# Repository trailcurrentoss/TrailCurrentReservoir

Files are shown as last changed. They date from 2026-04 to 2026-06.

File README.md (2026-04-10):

# TrailCurrent Reservoir

Water tank level monitoring module that reads contactless level sensors on up to three tanks (fresh, grey, black water) and transmits fill percentages over a CAN bus interface. Part of the [TrailCurrent](https://trailcurrent.com) open-source vehicle platform.

## Hardware Overview

- **Board:** Waveshare ESP32-S3-RS485-CAN
- **Microcontroller:** ESP32-S3
- **Framework:** ESP-IDF with FreeRTOS
- **Function:** Contactless water level sensors to CAN bus bridge
- **Key Features:**
  - Monitors up to 3 water tanks (fresh, grey, black)
  - 4 contactless level sensors per tank (25%, 50%, 75%, 100%)
  - Reports tank levels as 0-100% over CAN bus
  - Percentage-based protocol supports future migration to analog sensors
  - CAN bus output at 500 kbps (TWAI normal mode)
  - Automatic CAN bus recovery from bus-off errors
  - Nodes can enter and leave the network without disrupting the bus
  - Dedicated FreeRTOS tasks for CAN and sensor polling
  - CAN-triggered OTA firmware updates over WiFi (HTTP upload)
  - WiFi credential provisioning via CAN bus
  - Dual OTA partition table for safe updates with rollback
  - 80 MHz CPU clock for reduced power consumption

## Hardware Requirements

### Components

- **Board:** [Waveshare ESP32-S3-RS485-CAN](https://www.waveshare.com/wiki/ESP32-S3-RS485-CAN#Schematic)
- **CAN Bus:** Built-in transceiver (TX: GPIO 15, RX: GPIO 16, 500 kbps)
- **Sensors:** 12x contactless water level sensors (active HIGH output when water detected)
- **Debug Console:** USB CDC (115200 baud)

### Pin Assignments

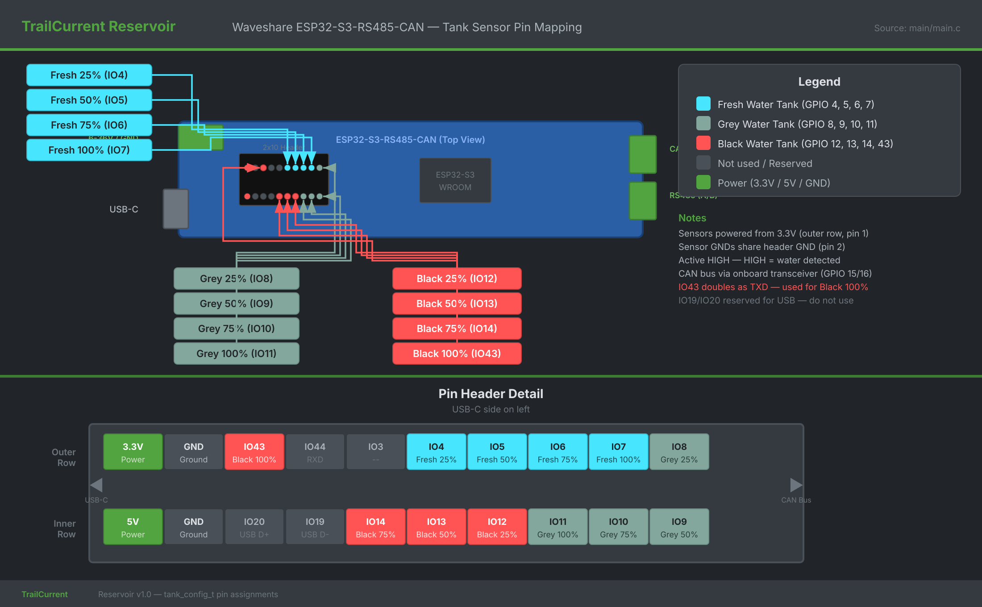
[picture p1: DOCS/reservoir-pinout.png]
Board Pin Mapping


| Function | GPIO | Description |
|---|---|---|
| CAN TX | 15 | CAN bus transmit (onboard transceiver) |
| CAN RX | 16 | CAN bus receive (onboard transceiver) |
| Fresh 25% | 4 | Fresh water tank, 25% level sensor |
| Fresh 50% | 5 | Fresh water tank, 50% level sensor |
| Fresh 75% | 6 | Fresh water tank, 75% level sensor |
| Fresh 100% | 7 | Fresh water tank, 100% level sensor |
| Grey 25% | 8 | Grey water tank, 25% level sensor |
| Grey 50% | 9 | Grey water tank, 50% level sensor |
| Grey 75% | 10 | Grey water tank, 75% level sensor |
| Grey 100% | 11 | Grey water tank, 100% level sensor |
| Black 25% | 12 | Black water tank, 25% level sensor |
| Black 50% | 13 | Black water tank, 50% level sensor |
| Black 75% | 14 | Black water tank, 75% level sensor |
| Black 100% | 43 | Black water tank, 100% level sensor |

All sensor GPIOs are configured as inputs with internal pull-down resistors.

### Ribbon Cable Pinout

When connecting via a 20-pin IDC ribbon cable, the red stripe aligns with pin 1 (3.3V/5V end). The sensor wires are interleaved due to standard odd/even row numbering.

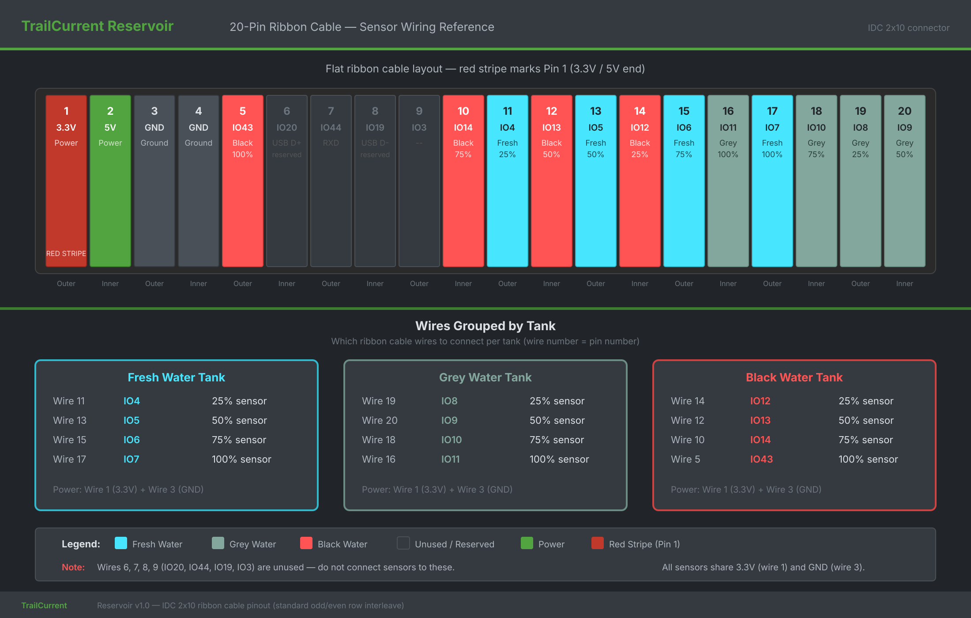
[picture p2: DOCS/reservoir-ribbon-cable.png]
Ribbon Cable Pinout


## Firmware

The firmware uses ESP-IDF with FreeRTOS. Source is in the `main/` directory.

### Prerequisites

- [ESP-IDF v5.5+](https://docs.espressif.com/projects/esp-idf/en/stable/esp32s3/get-started/)

### Build and Flash

```bash
# Set ESP-IDF environment
. $HOME/esp/esp-idf/export.sh

# Build
idf.py build

# Flash via USB (development)
idf.py -p /dev/ttyACM0 flash

# Monitor serial output
idf.py -p /dev/ttyACM0 monitor
```

### Creating Release Binaries

The standard `idf.py build` produces `build/reservoir.bin` — the application image only. This is the correct binary for OTA updates, where Headwaters writes it directly to an app partition via the device's `/ota` HTTP endpoint.

The TrailCurrent web flasher needs a different binary: a merged image containing the bootloader, partition table, OTA data, and application combined into a single file that gets flashed at offset 0x0. Without this, the web flasher would write the application binary to the wrong flash offset, resulting in a non-booting device.

After building, run the merge script to create the merged binary:

```bash
idf.py build
./merge.sh
```

This produces two files in `build/`:

| File | Contents | Used By |
|---|---|---|
| `reservoir.bin` | Application image only | Headwaters OTA (`deploy.sh`, `ota.js`), direct `curl` uploads |
| `reservoir_merged.bin` | Bootloader + partition table + OTA data + application | Web flasher (full flash at 0x0) |

**Both files must be attached to each GitHub release:**

```bash
git tag -a v1.0.0 -m "Firmware release v1.0.0"
git push origin v1.0.0

gh release create v1.0.0 \
  build/reservoir.bin \
  build/reservoir_merged.bin \
  --repo trailcurrentoss/TrailCurrentReservoir \
  --title "v1.0.0" \
  --notes "Firmware release v1.0.0"
```

The web flasher matches `reservoir_merged.bin` by the "merged" keyword in the filename. The Headwaters deployment system (`fetch-firmware.sh`) downloads the app-only `reservoir.bin` for OTA delivery.

### Architecture

The firmware runs two FreeRTOS tasks:

- **Main task** - Polls all 12 water level sensor GPIOs every 500ms and converts binary sensor states to tank fill percentages.
- **TWAI task** - Manages the CAN bus independently on core 1. Handles bus-off detection, automatic recovery, and periodic non-blocking transmission of tank levels. Bus errors never stall sensor polling.

See [DOCS/firmware-architecture.md](DOCS/firmware-architecture.md) for detailed architecture documentation.

### CAN Bus Recovery

The TWAI driver runs in **normal mode** with full alert handling:

1. **Bus-off detected** - Transmissions stop, `twai_initiate_recovery()` is called
2. **Bus recovered** - Driver restarts via `twai_start()`, transmissions resume
3. **Error passive** - Logged as a warning (typically means no peers are ACKing)

This allows nodes to be connected and disconnected from the bus at any time without crashing the firmware or requiring a reboot.

### Sensor Reading Logic

Water rises from bottom to top, triggering sensors sequentially. The reported level equals the highest sensor reading HIGH:

| Sensors Triggered | Reported Level |
|---|---|
| None | 0% |
| 25% only | 25% |
| 25% + 50% | 50% |
| 25% + 50% + 75% | 75% |
| All four | 100% |

If a tank is not physically connected, all its sensors remain LOW and the level reports 0%.

### CAN Bus Protocol

The device communicates at 500 kbps using standard 11-bit CAN IDs.

**Received Messages:**

| CAN ID | Name | Description |
|---|---|---|
| 0x00 | OTA Trigger | 3 bytes: target device MAC (last 3 bytes). Enters OTA mode if matched. |
| 0x01 | WiFi Config | Chunked credential provisioning (start/SSID chunks/password chunks/end). |
| 0x02 | Discovery | Broadcast trigger for mDNS self-discovery. |

**Transmitted Messages:**

| CAN ID | Name | Cycle | Description |
|---|---|---|---|
| 0x04 | Version Report | Once at boot | `[mac3, mac4, mac5, major, minor, patch]` |
| 0x3E | WaterTankLevels | 1000ms | 3 bytes: fresh %, grey %, black % |

**Message 0x3E - WaterTankLevels** (3 bytes):

| Byte | Signal | Range | Unit | Description |
|---|---|---|---|---|
| 0 | FreshWaterLevel | 0-100 | % | Fresh water tank fill level |
| 1 | GreyWaterLevel | 0-100 | % | Grey water tank fill level |
| 2 | BlackWaterLevel | 0-100 | % | Black water tank fill level |

See [DOCS/can-protocol.md](DOCS/can-protocol.md) for full protocol details including encoding examples and future analog sensor considerations.

### OTA Firmware Updates

The device supports over-the-air firmware updates triggered via CAN bus, matching the TrailCurrent OTA protocol used across all nodes.

**How it works:**

1. Headwaters (Raspberry Pi) sends CAN ID `0x00` with the target device's last 3 MAC bytes
2. If the MAC matches, the device connects to WiFi and starts an HTTP server
3. Firmware is uploaded via HTTP POST to the device
4. After upload, the device reboots into the new firmware
5. If no upload arrives within 3 minutes, WiFi disconnects and normal operation resumes

**Uploading firmware:**

OTA writes only to the app partition, so always use `reservoir.bin` (the app-only binary), never `reservoir_merged.bin`. The merged binary contains the bootloader and partition table, which would fail the app image validation in `esp_ota_end`.

```bash
# Find device hostname from serial output (e.g., esp32-8A3B4C)
# After OTA mode is triggered:
curl -X POST http://esp32-XXYYZZ.local/ota --data-binary @build/reservoir.bin
```

**WiFi credential provisioning:**

WiFi credentials are stored in NVS and provisioned via CAN ID `0x01` using a chunked message protocol. See the TrailCurrent CAN Bus Reference for the full specification.

**Partition layout:**

The device uses a dual OTA partition scheme for safe updates with automatic rollback:

| Partition | Type | Size |
|---|---|---|
| nvs | data (nvs) | 20 KB |
| otadata | data (ota) | 8 KB |
| app0 | app (ota_0) | 1792 KB |
| app1 | app (ota_1) | 1792 KB |
| spiffs | data (spiffs) | 448 KB |

## Documentation

Detailed documentation is available in the [DOCS/](DOCS/) directory:

- [High-Level Requirements](DOCS/Requirements/high-level-requirements.md) - System requirements and design rationale
- [Firmware Architecture](DOCS/firmware-architecture.md) - Task structure, data flow, and timing
- [CAN Protocol](DOCS/can-protocol.md) - Complete CAN message specification
- [Sensor Wiring Guide](DOCS/sensor-wiring.md) - Installation, wiring, and troubleshooting
- [Board Pin Mapping](DOCS/reservoir-pinout.svg) - GPIO-to-sensor visual pin diagram
- [Ribbon Cable Pinout](DOCS/reservoir-ribbon-cable.svg) - 20-pin IDC ribbon cable wiring reference

## Project Structure

```
├── DOCS/                             # Detailed documentation
│   ├── Requirements/
│   │   └── high-level-requirements.md
│   ├── firmware-architecture.md
│   ├── can-protocol.md
│   ├── sensor-wiring.md
│   ├── reservoir-pinout.svg          # Board pin mapping diagram
│   ├── reservoir-pinout.png
│   ├── reservoir-ribbon-cable.svg    # Ribbon cable wiring diagram
│   └── reservoir-ribbon-cable.png
├── main/                             # ESP-IDF firmware source
│   ├── main.c                        # Sensor polling and CAN transmitter
│   ├── wifi_config.c                 # WiFi credential management via CAN
│   ├── wifi_config.h
│   ├── ota.c                         # OTA update, WiFi, mDNS
│   ├── ota.h
│   ├── discovery.c                   # mDNS self-discovery
│   ├── discovery.h
│   ├── idf_component.yml             # Component dependencies
│   └── CMakeLists.txt                # Component registration
├── partitions.csv                    # Dual OTA partition table
├── CMakeLists.txt                    # ESP-IDF root build file
├── merge.sh                          # Creates merged binary for web flasher / releases
└── sdkconfig.defaults                # ESP-IDF default configuration
```

## License

MIT License - See LICENSE file for details.

This is open source hardware. You are free to use, modify, and distribute these designs under the terms of the MIT license.

## Contributing

Improvements and contributions are welcome! Please submit issues or pull requests.

## Support

For questions about:
- **KiCAD setup:** See [KICAD_ENVIRONMENT_SETUP.md](https://github.com/trailcurrentoss/TrailCurrentKiCADLibraries/blob/main/KICAD_ENVIRONMENT_SETUP.md)
- **Assembly workflow:** See [BOM_ASSEMBLY_WORKFLOW.md](https://github.com/trailcurrentoss/TrailCurrentKiCADLibraries/blob/main/BOM_ASSEMBLY_WORKFLOW.md)

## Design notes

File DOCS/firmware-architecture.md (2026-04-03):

# Firmware Architecture

## Overview

The Reservoir firmware is an ESP-IDF application that polls contactless water level sensors and broadcasts tank fill percentages over a CAN bus. It follows the same architectural patterns as other TrailCurrent modules (Ampline, Solstice, Picket) with dedicated FreeRTOS tasks for CAN and application logic.

## Task Structure

| Task | Core | Priority | Stack | Function |
|---|---|---|---|---|
| Main (app_main) | 0 | 1 (default) | default | Sensor polling loop |
| TWAI | 1 | 5 | 4096 B | CAN bus TX/RX and error handling |
| OTA | any | 3 | 8192 B | On-demand: WiFi + HTTP OTA server |
| Discovery | any | 3 | 8192 B | On-demand: mDNS registration |

The OTA and Discovery tasks are mutually exclusive and only run when triggered by a CAN message. They are created dynamically and delete themselves on completion.

## Data Flow

```
Sensors (GPIO)          Shared Memory           CAN Bus
 ┌──────────┐          ┌──────────────┐        ┌──────────┐
 │ 12 GPIOs │──poll──> │ tank_levels  │──read─>│ TWAI TX  │──> CAN ID 0x3E
 │ (500ms)  │          │ [3 x uint8]  │        │ (1000ms) │
 └──────────┘          └──────────────┘        └──────────┘
   Main Task            volatile array          TWAI Task
```

1. **Main task** reads all 12 GPIO pins every 500ms
2. For each tank, it determines the highest triggered sensor and writes the percentage to `tank_levels[]`
3. **TWAI task** reads `tank_levels[]` every 1000ms and packs it into a 3-byte CAN message
4. Single-writer (main task) / single-reader (TWAI task) pattern with `volatile` — no mutex needed

## Sensor-to-Percentage Conversion

Each tank has 4 sensors mounted at physical water levels corresponding to 25%, 50%, 75%, and 100%. The sensors are indexed from lowest (index 0 = 25%) to highest (index 3 = 100%).

```c
static uint8_t read_tank_level(const tank_config_t *tank)
{
    uint8_t level = 0;
    for (int s = 0; s < NUM_SENSORS; s++) {
        if (gpio_get_level(tank->pins[s])) {
            level = (s + 1) * 25;
        }
    }
    return level;
}
```

The loop iterates from the lowest sensor upward. Each HIGH sensor overwrites the level, so the final value is the highest triggered sensor. This handles the normal case where water triggers all sensors below the surface.

**Edge cases:**

| Scenario | Sensor States (25/50/75/100) | Result |
|---|---|---|
| Empty tank | LOW/LOW/LOW/LOW | 0% |
| Quarter full | HIGH/LOW/LOW/LOW | 25% |
| Half full | HIGH/HIGH/LOW/LOW | 50% |
| Three-quarter full | HIGH/HIGH/HIGH/LOW | 75% |
| Full | HIGH/HIGH/HIGH/HIGH | 100% |
| No tank connected | LOW/LOW/LOW/LOW | 0% |
| Sensor skip (50% stuck LOW) | HIGH/LOW/HIGH/LOW | 75% |

The last case (sensor skip) reports the highest triggered sensor regardless of gaps. This is intentional — a stuck-low sensor should not suppress the reading from higher sensors.

## GPIO Configuration

All 12 sensor GPIOs are configured in a single `gpio_config()` call at startup:

- **Mode:** Input
- **Pull-up:** Disabled
- **Pull-down:** Enabled (internal)
- **Interrupt:** Disabled (polling-based)

The internal pull-down ensures a clean LOW reading when no sensor is connected or when the sensor is not triggered. The contactless sensors drive the GPIO HIGH when water is detected.

## CAN Bus State Machine

The TWAI task implements the same bus state machine used across all TrailCurrent modules:

```
                 ┌─────────────┐
     boot ──────>│  TX_ACTIVE  │<──── TX_SUCCESS or RX_DATA
                 │  (1000ms)   │
                 └──────┬──────┘
                        │ 3x TX_FAILED
                        v
                 ┌─────────────┐
                 │ TX_PROBING  │───── TX_SUCCESS ────> TX_ACTIVE
                 │  (2000ms)   │
                 └──────┬──────┘
                        │ BUS_OFF
                        v
                 ┌─────────────┐
                 │  RECOVERY   │───── BUS_RECOVERED ──> TX_PROBING
                 │  (waiting)  │
                 └─────────────┘
```

- **TX_ACTIVE:** Normal operation, transmits every 1000ms
- **TX_PROBING:** No peers on bus, slows to 2000ms to reduce error load
- **RECOVERY:** Bus-off detected, driver recovery in progress, no transmissions

## Startup Sequence

1. Initialize NVS and load WiFi credentials (if previously provisioned)
2. Initialize Discovery and OTA subsystems
3. Configure all 12 sensor GPIOs with pull-downs
4. Log hostname and pin assignments
5. Start TWAI task on core 1
6. Broadcast firmware version on CAN ID 0x04
7. Enter main loop: poll sensors every 500ms

## Source Files

| File | Lines | Purpose |
|---|---|---|
| `main.c` | ~250 | Sensor GPIO config, polling, TWAI task, CAN message packing |
| `wifi_config.c` | ~280 | NVS credential storage, CAN-based WiFi provisioning state machine |
| `wifi_config.h` | ~15 | WiFi config public API |
| `ota.c` | ~220 | HTTP OTA server, firmware write, CAN trigger handling |
| `ota.h` | ~28 | OTA public API |
| `discovery.c` | ~175 | mDNS advertisement, Headwaters confirmation endpoint |
| `discovery.h` | ~28 | Discovery public API |

## Timing Summary

| Event | Interval | Notes |
|---|---|---|
| Sensor poll | 500ms | Main task loop delay |
| CAN TX (active) | 1000ms | Normal operation with peers |
| CAN TX (probing) | 2000ms | No peers detected |
| WiFi config timeout | 5s | Resets chunked credential state machine |
| OTA timeout | 3 min | Disconnects WiFi if no upload received |
| Discovery timeout | 3 min | Disconnects WiFi if no confirmation |

## Memory Usage

The firmware has minimal RAM requirements:

- **Shared state:** 3 bytes (`tank_levels[3]`, volatile uint8)
- **No heap allocations** in the sensor polling or CAN transmission paths
- **Stack sizes:** Main task uses default (~3.5 KB), TWAI task uses 4 KB
- **OTA/Discovery:** 8 KB stack each, only allocated when triggered

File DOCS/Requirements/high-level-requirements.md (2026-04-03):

# High-Level Design (HLD) Document

## 1. Project Overview

**Project Title:** Reservoir Module

**Description:** A microcontroller-based system that monitors the fill level of up to three water tanks (fresh, grey, black) using contactless level sensors and reports the data over CAN bus. It enables the TrailCurrent platform to display real-time water levels and trigger alerts when tanks are full or empty.

**Objective:**
To design and implement a reliable, low-power, and cost-effective water tank monitoring system that reports fill levels as percentages over CAN bus, with a protocol that supports future migration from binary contactless sensors to analog level sensors without any CAN message format changes.

---

## 2. Microcontroller Selection

**Selected Microcontroller:**
**ESP32-S3** (Waveshare ESP32-S3-RS485-CAN)
[Datasheet](https://www.espressif.com/sites/default/files/documentation/esp32-s3_datasheet_en.pdf)

**Rationale for Selection:**
- Off-the-shelf board with onboard CAN transceiver (TJA1051), buck converter (7-36V), and 20-pin header for sensor connections.
- 12 GPIOs available on pin header with internal pull-downs for sensor inputs.
- Strong ecosystem and ESP-IDF development support.
- Shared board with Solstice and Picket modules, reducing BOM complexity.
- No external pull-down resistors needed (internal pull-downs are sufficient for active-high sensor outputs).

---

## 3. System Requirements

### 3.1 Functional Requirements

| Requirement | Description |
|---|---|
| Tank Level Sensing | Read contactless water level sensors and determine fill level for each of 3 tanks |
| Percentage Reporting | Report each tank level as a 0-100% value, not as individual sensor states |
| CAN Transmission | Broadcast all 3 tank levels in a single CAN message at 1-second intervals |
| Multi-Tank Support | Support fresh water, grey water, and black water tanks independently |
| Graceful Degradation | Report 0% for any tank that has no sensors connected |
| OTA Updates | Support over-the-air firmware updates triggered via CAN bus |
| WiFi Provisioning | Accept WiFi credentials via CAN bus for OTA connectivity |
| Network Discovery | Respond to mDNS discovery broadcasts for Headwaters registration |

### 3.2 Non-Functional Requirements

| Requirement | Description |
|---|---|
| Reliability | System must operate continuously without disruption indefinitely for solar/off-grid installs |
| Protocol Agnosticism | CAN message format must not change if sensors are upgraded from binary to analog |
| Power Consumption | 80 MHz CPU clock to minimize power draw on house battery systems |
| Environmental Tolerance | Operate within -20C to +70C |
| Response Time | Sensor polling at 500ms intervals for timely level updates |
| Bus Resilience | CAN bus errors must not halt sensor polling; automatic bus recovery required |

---

## 4. System Architecture Overview

### 4.1 Hardware Components

| Component | Description |
|---|---|
| ESP32-S3 (Waveshare ESP32-S3-RS485-CAN) | Main microcontroller with onboard CAN transceiver |
| Contactless Water Level Sensors (x12) | Active-high output sensors, 4 per tank at 25/50/75/100% marks |
| CAN Bus Wiring | Standard 2-wire CAN bus (CANH, CANL) with 120-ohm termination |

### 4.2 Software Components

| Component | Description |
|---|---|
| Main Application | Sensor polling, level calculation, and shared data management |
| TWAI Task | CAN bus communication, error handling, and periodic message transmission |
| WiFi Config | NVS-backed WiFi credential storage with CAN-based provisioning |
| OTA | Over-the-air firmware update via HTTP with CAN-triggered activation |
| Discovery | mDNS-based module registration with Headwaters |

---

## 5. Communication Protocol

- **CAN Bus:** 500 kbps, standard 11-bit IDs, TWAI normal mode
- **Message ID:** 0x3E (WaterTankLevels)
- **Data Format:** 3 bytes, each a uint8 representing 0-100% fill level
- **Transmission Frequency:** 1 Hz (1000ms cycle), slows to 0.5 Hz when no CAN peers detected
- **Byte Layout:** `[fresh%, grey%, black%]`

### Protocol Design Decision: Percentages Over Sensor States

The CAN protocol transmits percentage values (0-100) rather than individual sensor booleans. This is intentional:

- **Current sensors (contactless binary):** Values are quantized to 0/25/50/75/100%
- **Future sensors (analog/continuous):** Values can be any integer 0-100%
- **CAN message format stays identical** regardless of sensor technology
- Receivers (Headwaters, mobile app, dashboards) never need to know how the percentage was derived

---

## 6. Power Management Strategy

- **Battery:** Connected to house battery of implemented vehicle
- **Power Supply Circuit:** Waveshare board includes 7-36V input with onboard buck converter and 3.3V regulator
- **CPU Clock:** 80 MHz (reduced from default 240 MHz) for lower power consumption
- **Sleep Modes:** Not used; the module must report continuously for real-time monitoring

---

## 7. Development Tools and Environment

| Tool | Description |
|---|---|
| ESP-IDF | Development framework (v5.5+) |
| VS Code | Development IDE |
| KiCAD | EDA design tool for schematic and PCB (future hardware design) |
| FreeCAD | CAD tool for enclosure design (future) |
| Version Control | Git with GitHub for repo and source control |
| Documentation Tools | Markdown |

---

## 8. Testing and Validation

| Test Type | Description |
|---|---|
| Unit Testing | Verify sensor-to-percentage conversion logic for all input combinations |
| Integration Testing | Validate CAN message transmission with Headwaters and mobile app |
| Sensor Validation | Test with sensors submerged at known water levels to confirm correct reporting |
| Bus Resilience | Disconnect and reconnect CAN bus during operation; verify automatic recovery |
| OTA Testing | Trigger OTA update via CAN; verify firmware upload and reboot cycle |
| Multi-Tank | Test with 1, 2, and 3 tanks connected to verify independent reporting |

---

## 9. Future Enhancements

- Migrate to analog level sensors for continuous 0-100% reporting (no CAN protocol changes needed)
- Add temperature compensation for sensor readings
- Add leak detection (unexpected level drop alerts)
- Add tank capacity configuration via CAN for volumetric reporting (liters/gallons)
- Hardware design (KiCAD schematic, PCB, FreeCAD enclosure) for a dedicated Reservoir board

---

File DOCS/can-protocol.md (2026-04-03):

# CAN Bus Protocol

## Bus Configuration

| Parameter | Value |
|---|---|
| Bit Rate | 500 kbps |
| ID Format | Standard (11-bit) |
| Mode | TWAI Normal |
| Filter | Accept all |

## Message Summary

### Transmitted by Reservoir

| CAN ID | Name | DLC | Cycle | Description |
|---|---|-----|---|---|
| 0x04 | FirmwareVersionReport | 6 | Once at boot | Device MAC + firmware version |
| 0x3E | WaterTankLevels | 3 | 1000ms | Fill level of all 3 tanks |

### Received by Reservoir

| CAN ID | Name | DLC | Source | Description |
|---|---|-----|---|---|
| 0x00 | OtaUpdateNotification | 3 | Headwaters | MAC-targeted OTA trigger |
| 0x01 | WiFiConfig | 1-8 | Headwaters | Chunked WiFi credential provisioning |
| 0x02 | DiscoveryTrigger | 0 | Headwaters | Broadcast mDNS discovery trigger |

## Message 0x3E: WaterTankLevels

**Direction:** Reservoir -> Bus (broadcast)
**DLC:** 3 bytes
**Cycle time:** 1000ms (active), 2000ms (probing)
**DBC definition:** `BO_ 62 WaterTankLevels: 3 Reservoir`

### Byte Layout

| Byte | Signal Name | Type | Range | Unit | Description |
|---|---|---|---|---|---|
| 0 | FreshWaterLevel | uint8 | 0-100 | % | Fresh water tank fill level |
| 1 | GreyWaterLevel | uint8 | 0-100 | % | Grey water tank fill level |
| 2 | BlackWaterLevel | uint8 | 0-100 | % | Black water tank fill level |

### DBC Signal Definitions

```dbc
SG_ FreshWaterLevel : 7|8@0+ (1,0) [0|100] "%" Headwaters
SG_ GreyWaterLevel : 15|8@0+ (1,0) [0|100] "%" Headwaters
SG_ BlackWaterLevel : 23|8@0+ (1,0) [0|100] "%" Headwaters
```

Signal encoding: big-endian (Motorola), unsigned, factor=1, offset=0, no scaling.

### Encoding Examples

**All tanks empty:**
```
CAN ID: 0x3E  DLC: 3  Data: [0x00, 0x00, 0x00]
Fresh: 0%  Grey: 0%  Black: 0%
```

**Fresh half full, grey quarter, black empty:**
```
CAN ID: 0x3E  DLC: 3  Data: [0x32, 0x19, 0x00]
Fresh: 50%  Grey: 25%  Black: 0%
```

**All tanks full:**
```
CAN ID: 0x3E  DLC: 3  Data: [0x64, 0x64, 0x64]
Fresh: 100%  Grey: 100%  Black: 100%
```

**Fresh 75%, grey full, black 25%:**
```
CAN ID: 0x3E  DLC: 3  Data: [0x4B, 0x64, 0x19]
Fresh: 75%  Grey: 100%  Black: 25%
```

### Current Sensor Quantization

With the current contactless binary sensors, values are quantized to 5 discrete levels:

| Hex Value | Decimal | Level |
|---|---|---|
| 0x00 | 0 | Empty |
| 0x19 | 25 | Quarter |
| 0x32 | 50 | Half |
| 0x4B | 75 | Three-quarter |
| 0x64 | 100 | Full |

### Future Analog Sensor Values

When analog sensors are installed, values can be any integer from 0 to 100. The CAN message format remains identical. Receivers do not need to distinguish between sensor types; they simply display the percentage.

Example with analog sensors:
```
CAN ID: 0x3E  DLC: 3  Data: [0x43, 0x1D, 0x08]
Fresh: 67%  Grey: 29%  Black: 8%
```

## Message 0x04: FirmwareVersionReport

**Direction:** Reservoir -> Bus (broadcast)
**DLC:** 6 bytes
**Cycle time:** Once at startup
**Shared with:** All TrailCurrent modules

| Byte | Signal Name | Description |
|---|---|---|
| 0 | MacAddressByte4 | WiFi MAC address byte 4 |
| 1 | MacAddressByte5 | WiFi MAC address byte 5 |
| 2 | MacAddressByte6 | WiFi MAC address byte 6 |
| 3 | VersionMajor | Firmware major version |
| 4 | VersionMinor | Firmware minor version |
| 5 | VersionPatch | Firmware patch version |

The MAC bytes combined with the firmware version allow Headwaters to track which firmware each device is running.

## Message 0x00: OtaUpdateNotification

**Direction:** Headwaters -> Bus (broadcast, MAC-targeted)
**DLC:** 3 bytes

| Byte | Description |
|---|---|
| 0 | Target MAC byte 4 |
| 1 | Target MAC byte 5 |
| 2 | Target MAC byte 6 |

Only the device whose MAC matches enters OTA mode. All other devices ignore the message.

## Message 0x01: WiFiConfig

**Direction:** Headwaters -> Bus
**DLC:** 1-8 bytes (varies by sub-message)

Multi-message chunked protocol for WiFi credential provisioning. See the TrailCurrent CAN Bus Reference for the full specification.

| Sub-type (byte 0) | Description |
|---|---|
| 0x01 | Start: declares SSID/password lengths and chunk counts |
| 0x02 | SSID chunk: 6 bytes of SSID data per message |
| 0x03 | Password chunk: 6 bytes of password data per message |
| 0x04 | End: XOR checksum for validation |

## Message 0x02: DiscoveryTrigger

**Direction:** Headwaters -> Bus (broadcast)
**DLC:** 0 bytes (no payload)

All modules with WiFi credentials respond by connecting to WiFi and advertising via mDNS. Reservoir advertises with:

| TXT Record | Value |
|---|---|
| type | reservoir |
| canid | 0x3E |
| fw | (firmware version string) |

## Headwaters Integration

Headwaters (the CAN-to-MQTT bridge) receives message 0x3E and publishes it as JSON over MQTT:

```json
{
  "fresh": 50,
  "grey": 25,
  "black": 0
}
```

The mobile app (Kotlin `WaterState` model and React Native `TankBar` component) expects integer percentage values in this format. The existing backend API endpoint (`vehicleRepository.getWater()`) and WebSocket event (`WebSocketEvent.Water`) are already designed for percentage-based reporting.

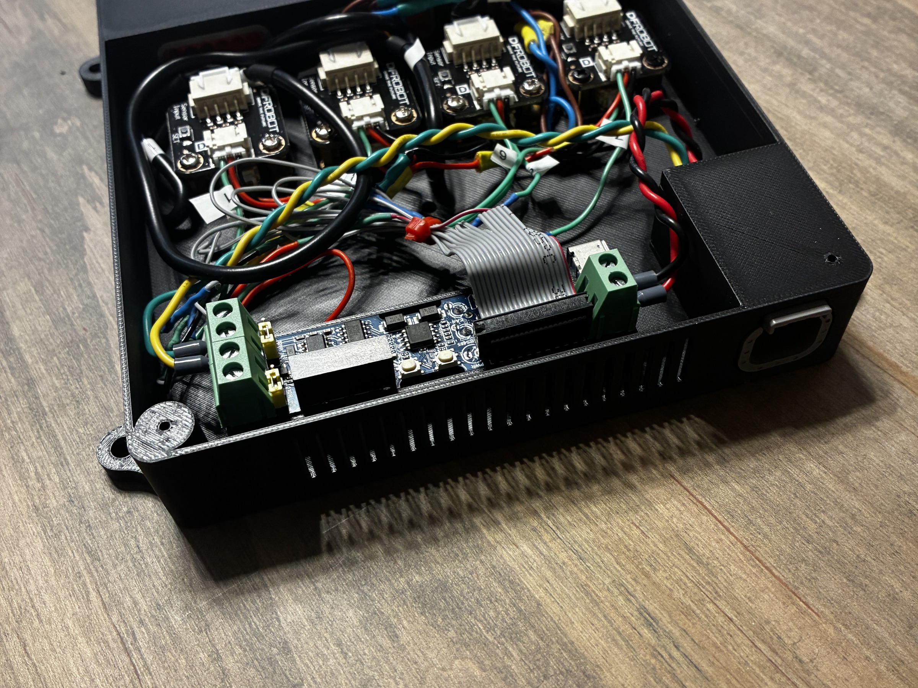
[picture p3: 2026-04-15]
DOCS/img/MakerworldPhotos/ModelPic_04_InternalElectronics.jpg

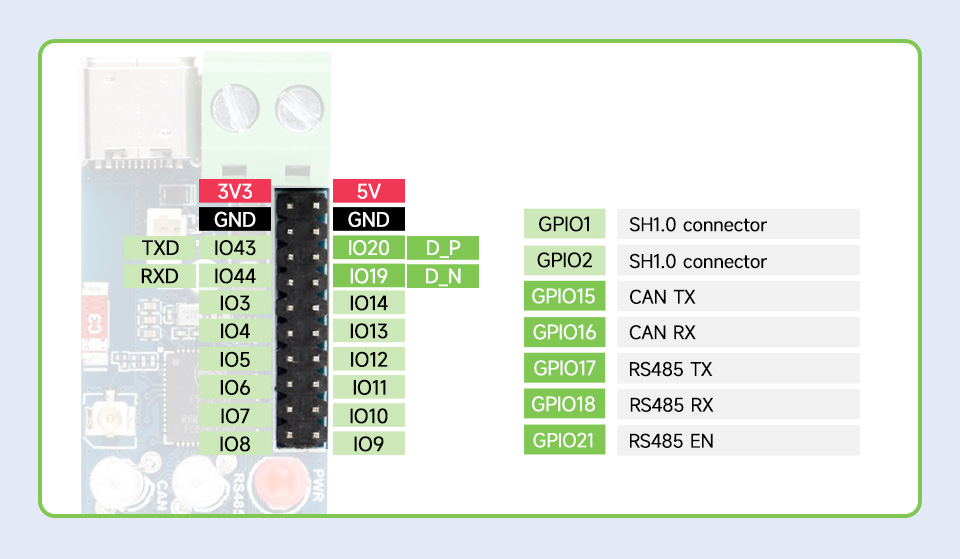
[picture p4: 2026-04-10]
DOCS/ESP32-S3-RS485-CAN-details-15.jpg

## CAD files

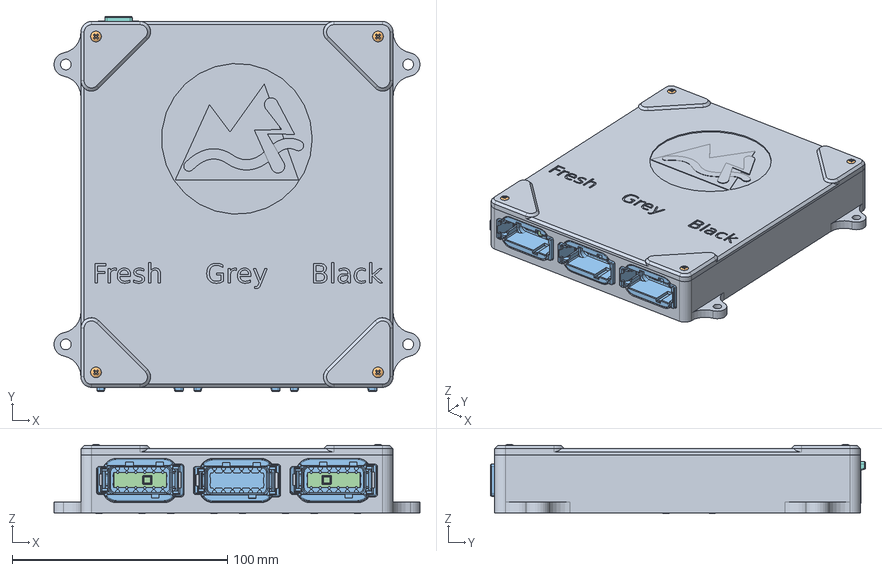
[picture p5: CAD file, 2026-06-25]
CAD/TrailCurrentReservoirHousing.FCStd
170.0 x 174.3 x 32.3 mm
BodyReservoirCaseBottom
M3x8-Screw x 12
C-DTM04-12PA x 3
JST_XH_S3B-XH-SM4-TB_1x03-1MP_P2.50mm_Horizontal001 x 12
JST_XH_S4B-XH-SM4-TB_1x04-1MP_P2.50mm_Horizontal001 x 12
M3x8x5.5-Spacer x 12
C-DTM04-4P
BodyRservoirCaseCover
M2.5x6-Screw x 4
C-WM-4P
C-WM-12P x 2

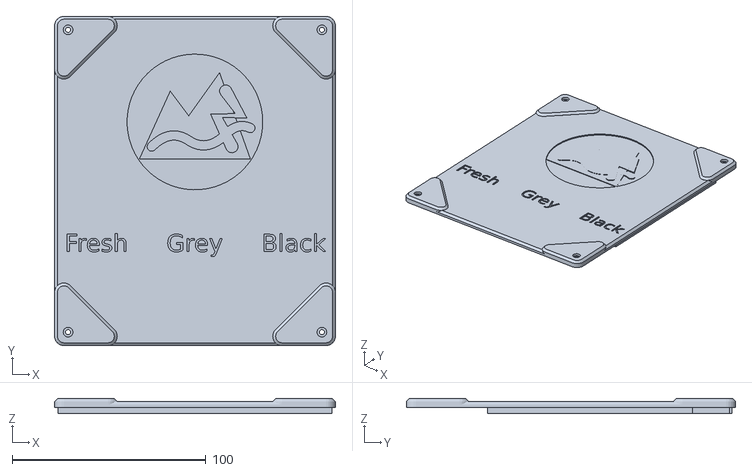
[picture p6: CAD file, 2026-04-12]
CAD/BodyRservoirCaseCover.stl
145.0 x 170.0 x 7.50

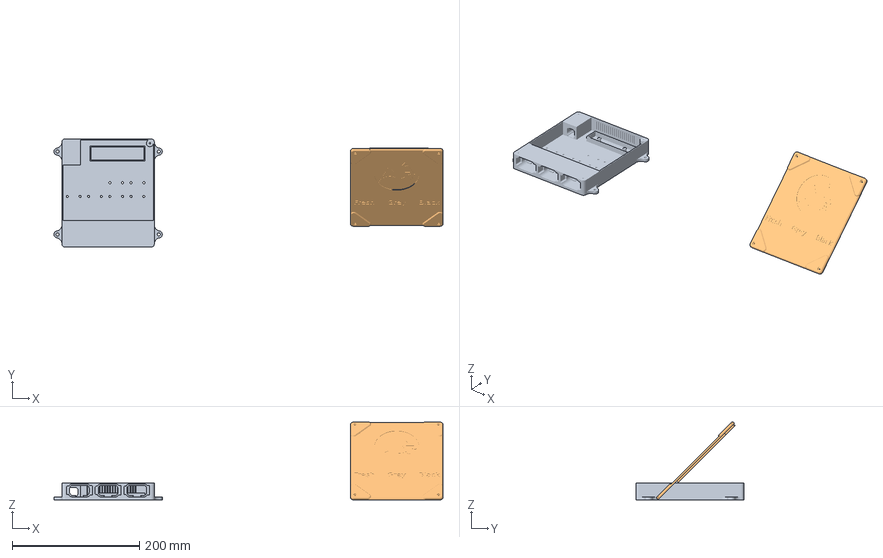
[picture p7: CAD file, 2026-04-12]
CAD/TrailCurrentReservoir.3mf
610.4 x 170.0 x 122.3 mm
BodyReservoirCaseBottomV4.stl
BodyRservoirCaseCover.stl

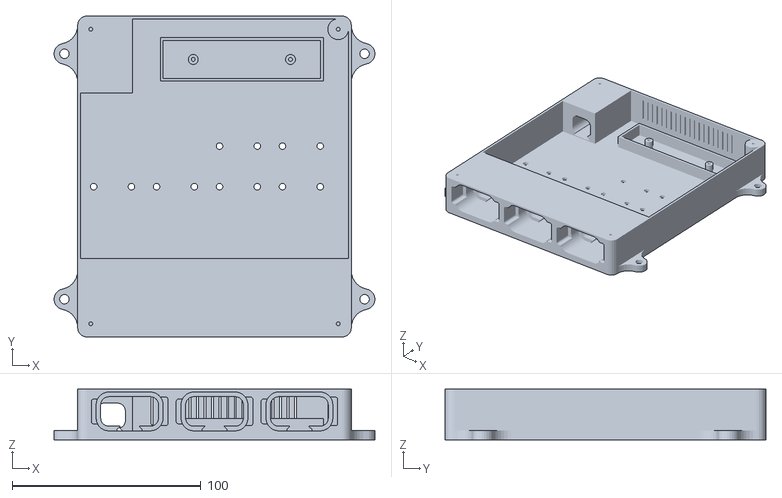
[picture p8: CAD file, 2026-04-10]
CAD/BodyReservoirCaseBottom.stl
169.9 x 170.0 x 26.9

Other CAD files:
CAD/TrailCurrentReservoir.blend

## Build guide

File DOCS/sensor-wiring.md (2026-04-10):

# Sensor Wiring Guide

## Sensor Overview

The Reservoir module uses contactless water level sensors that detect the presence of water through the tank wall without any penetration. Each sensor outputs a digital HIGH signal when water is present at its mounting position.

### Sensor Requirements

- **Type:** Contactless capacitive water level sensor (non-contact, external mount)
- **Output:** Digital HIGH when water detected, LOW when dry
- **Voltage:** 3.3V compatible (ESP32-S3 GPIO voltage)
- **Quantity:** 4 per tank, up to 12 total for 3 tanks

### Supported Sensors

Any contactless water level sensor with a digital HIGH/LOW output will work. Common options include:

- XKC-Y25-T12V (non-contact liquid level sensor)
- XKC-Y25-NPN or XKC-Y25-PNP variants (ensure 3.3V compatibility)

Verify the sensor's output voltage matches 3.3V logic levels. Some sensors are 5V or 12V output and require a voltage divider or level shifter.

## Wiring Diagram

### Per-Sensor Connection

Each sensor has 3 wires:

```
Sensor              ESP32-S3
┌──────────┐       ┌──────────┐
│ VCC (red)│───────│ 3.3V     │
│ GND (blk)│───────│ GND      │
│ OUT (yel)│───────│ GPIO xx  │
└──────────┘       └──────────┘
```

The ESP32-S3 GPIO is configured with an internal pull-down resistor. When the sensor detects water, it drives the GPIO HIGH. When dry, the pull-down holds the GPIO LOW.

### GPIO Pin Assignments

#### Fresh Water Tank

| Level | GPIO | Wire Color Suggestion |
|---|---|---|
| 25% | 4 | Blue |
| 50% | 5 | Green |
| 75% | 6 | Yellow |
| 100% | 7 | Red |

#### Grey Water Tank

| Level | GPIO | Wire Color Suggestion |
|---|---|---|
| 25% | 8 | Blue |
| 50% | 9 | Green |
| 75% | 10 | Yellow |
| 100% | 11 | Red |

#### Black Water Tank

| Level | GPIO | Wire Color Suggestion |
|---|---|---|
| 25% | 12 | Blue |
| 50% | 13 | Green |
| 75% | 14 | Yellow |
| 100% | 43 | Red |

### Power Wiring

All sensors share 3.3V and GND from the Waveshare board:

```
3.3V ──┬── Sensor 1 VCC
       ├── Sensor 2 VCC
       ├── ...
       └── Sensor 12 VCC

GND  ──┬── Sensor 1 GND
       ├── Sensor 2 GND
       ├── ...
       └── Sensor 12 GND
```

### CAN Bus Wiring

The CAN bus uses the onboard TJA1051 transceiver on the Waveshare board:

| Terminal | Connection |
|---|---|
| CANH | CAN bus high wire |
| CANL | CAN bus low wire |
| GND | CAN bus ground (shared) |

A 120-ohm termination resistor is required at each end of the CAN bus.

## Sensor Mounting

### Placement

Mount sensors on the **outside** of the tank wall at the desired measurement heights:

```
Tank (side view)
┌─────────────────┐
│                  │ ← 100% sensor (near top, leave room for expansion)
│                  │
│                  │ ← 75% sensor
│                  │
│                  │ ← 50% sensor (midpoint)
│                  │
│                  │ ← 25% sensor
│                  │
└──────────────────┘
```

### Mounting Guidelines

1. **Clean the tank surface** where each sensor will be mounted. Remove any dirt, grease, or residue.
2. **Adhere sensors firmly** to the tank wall. Most contactless sensors include adhesive backing or mounting brackets.
3. **Ensure flat contact** between the sensor face and the tank wall. Air gaps reduce sensitivity.
4. **Avoid mounting near:**
   - Tank seams or welds (uneven surface)
   - Heating elements or hot water lines
   - Metal reinforcements or brackets (may interfere with capacitive sensing)
5. **Vertical spacing** should divide the usable tank height into quarters. The 25% sensor goes at 1/4 height from the bottom, 100% near the top but below the overflow level.

### Tank Wall Compatibility

Contactless capacitive sensors work through:
- **Plastic tanks** (polyethylene, polypropylene) - best performance
- **Fiberglass tanks** - good performance
- **Thin metal tanks** - reduced sensitivity, may not work reliably

They do **not** work through thick metal walls. If your tank is metal, consider in-tank sensors with a sealed feedthrough.

## Partial Tank Configurations

Not all three tanks need to be connected. The firmware reports 0% for any tank with no sensors wired:

| Configuration | CAN Output |
|---|---|
| Fresh only | `[level, 0, 0]` |
| Fresh + Grey | `[level, level, 0]` |
| All three | `[level, level, level]` |
| Grey + Black only | `[0, level, level]` |

No firmware changes are needed. Unwired GPIOs read LOW (0%) due to the internal pull-down resistors.

## Troubleshooting

### Sensor Always Reads LOW (0%)

1. **Check wiring:** Verify VCC, GND, and signal connections
2. **Check voltage:** Measure sensor output with a multimeter while submerged — should be ~3.3V
3. **Check GPIO:** Verify the correct GPIO pin is connected (see pin assignment table)
4. **Check mounting:** Ensure sensor is firmly against the tank wall with no air gap
5. **Check tank material:** Metal tanks may block the capacitive signal

### Sensor Always Reads HIGH (stuck at that level)

1. **Check for moisture** on the outside of the tank near the sensor
2. **Check for condensation** between the sensor and tank wall
3. **Remove and re-mount** the sensor on a dry surface
4. **Check wire routing:** Signal wires running parallel to power wires can pick up noise

### Erratic Readings (level jumps between values)

1. **Add wire shielding** if signal cables run longer than 1 meter
2. **Keep sensor wires away** from high-current or high-frequency sources (inverters, motors)
3. **Check power supply:** Ensure 3.3V rail is clean and not sagging under load

### Only Some Tanks Report Data

1. **Check which GPIOs** are connected — each tank uses a specific set of 4 GPIOs
2. **Monitor serial output:** The firmware logs all pin assignments at startup
3. **Verify the GPIO numbers** match the physical wiring (not the board silkscreen pin numbers)

### CAN Bus Not Transmitting

1. **Check CAN wiring:** CANH to CANH, CANL to CANL, with 120-ohm termination
2. **Monitor serial output:** Look for "TWAI bus-off" or "error passive" messages
3. **Verify at least one other CAN node** is on the bus (TWAI normal mode requires ACK from a peer)
4. **Check the bus is not in probing mode** (serial output will say "entering slow probe") — this is normal when no peers are connected

## Modifying Pin Assignments

If you need to use different GPIOs (due to wiring constraints or a different board), edit the `tanks` array in `main/main.c`:

```c
static const tank_config_t tanks[NUM_TANKS] = {
    { "fresh", { GPIO_NUM_4,  GPIO_NUM_5,  GPIO_NUM_6,  GPIO_NUM_7  } },
    { "grey",  { GPIO_NUM_8,  GPIO_NUM_9,  GPIO_NUM_10, GPIO_NUM_11 } },
    { "black", { GPIO_NUM_12, GPIO_NUM_13, GPIO_NUM_14, GPIO_NUM_43 } },
};
```

**Avoid these GPIOs:**
- GPIO 0: Boot strapping pin
- GPIO 3: Boot strapping pin
- GPIO 15: CAN TX (used by onboard transceiver)
- GPIO 16: CAN RX (used by onboard transceiver)
- GPIO 19-20: USB D-/D+ (used for USB CDC console)
- GPIO 26-32: Flash SPI (reserved on most ESP32-S3 modules)
- GPIO 33-37: PSRAM (reserved on WROVER variants)
- GPIO 45-46: Boot strapping pins

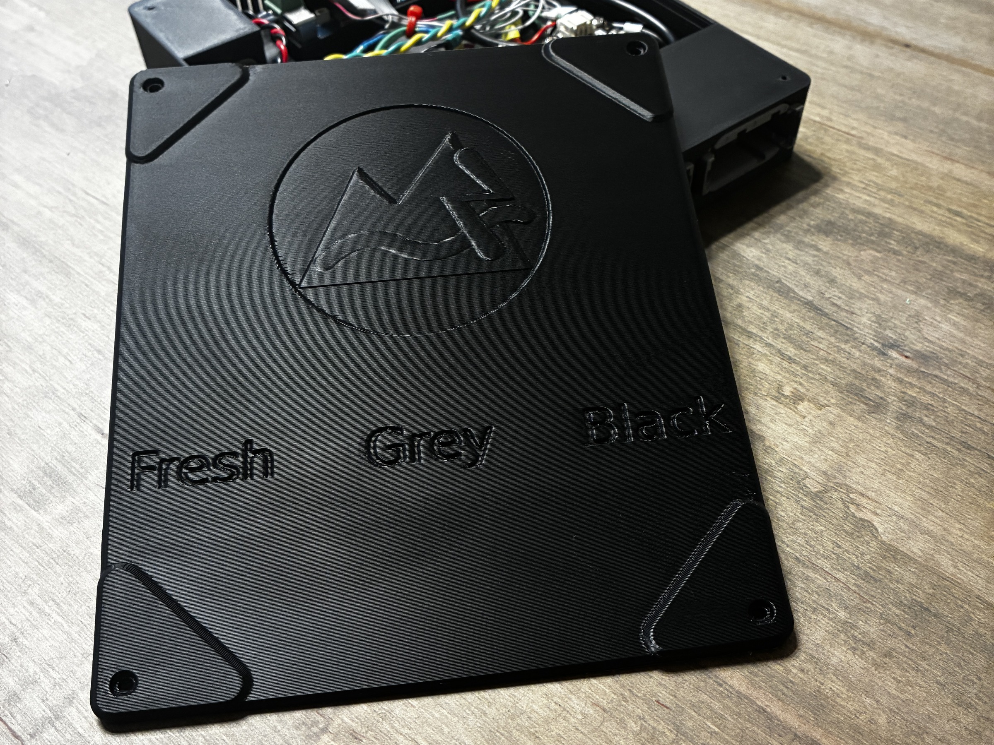
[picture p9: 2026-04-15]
DOCS/img/MakerworldPhotos/ModelPic_01_TopView_CoverOn.jpg

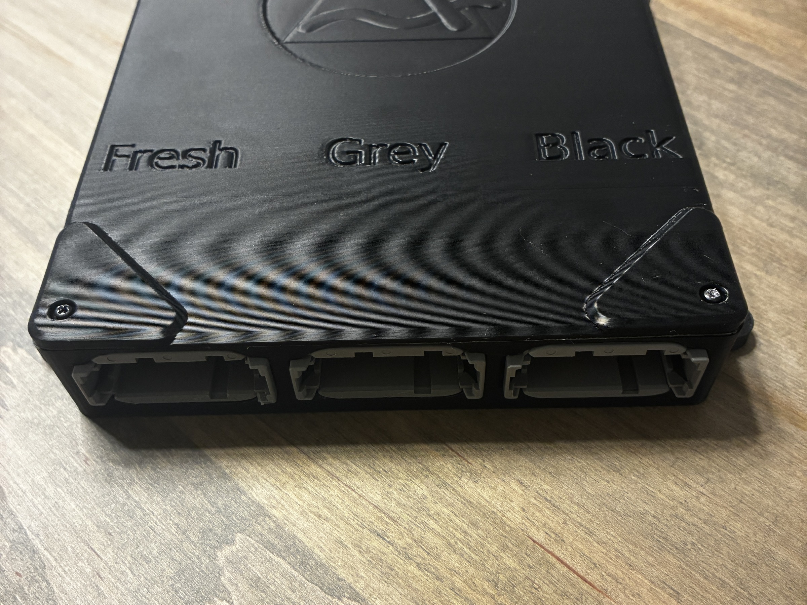
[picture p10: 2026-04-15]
DOCS/img/MakerworldPhotos/Cover_4x3_WebApp.jpg

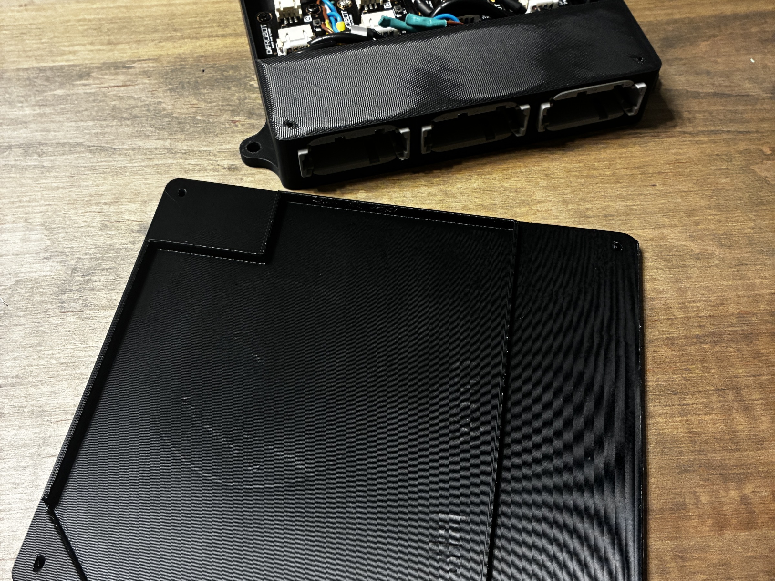
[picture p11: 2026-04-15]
DOCS/img/MakerworldPhotos/ModelPic_03_Exploded_InternalsAndCover.jpg

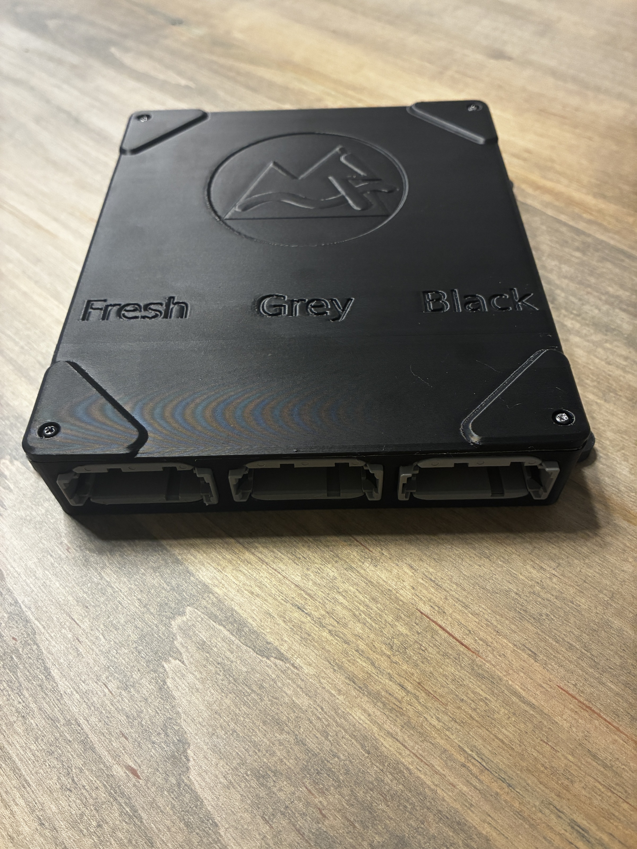
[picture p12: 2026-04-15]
DOCS/img/MakerworldPhotos/Cover_3x4_App.jpg

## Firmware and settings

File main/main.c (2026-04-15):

#include <stdio.h>
#include <string.h>
#include "freertos/FreeRTOS.h"
#include "freertos/task.h"
#include "driver/twai.h"
#include "driver/gpio.h"
#include "esp_log.h"
#include "esp_timer.h"
#include "can_common.h"
#include "wifi_config.h"
#include "ota.h"
#include "discovery.h"

static const char *TAG = "reservoir";

// Waveshare ESP32-S3-RS485-CAN pin assignments
#define CAN_RX_PIN           16
#define CAN_TX_PIN           15

// CAN protocol IDs
#define CAN_ID_OTA               0x00
#define CAN_ID_WIFI_CONFIG       0x01
#define CAN_ID_DISCOVERY_TRIGGER 0x02
#define CAN_ID_WATER_TANK_LEVELS 0x3E

// CAN transmit period in milliseconds
#define CAN_STATUS_PERIOD_MS 1000
#define TX_PROBE_INTERVAL_MS 2000  // slow probe when no peers detected

// Sensor poll interval
#define SENSOR_POLL_MS       500

// ---------------------------------------------------------------------------
// Water level sensor GPIO assignments
// Each tank has 4 contactless sensors at 25%, 50%, 75%, and 100% levels.
// Sensors output HIGH when water is detected (active high, pull-down).
// ---------------------------------------------------------------------------

#define NUM_TANKS   3
#define NUM_SENSORS 4

typedef struct {
    const char *name;
    gpio_num_t pins[NUM_SENSORS];  // index 0=25%, 1=50%, 2=75%, 3=100%
} tank_config_t;

static const tank_config_t tanks[NUM_TANKS] = {
    { "fresh", { GPIO_NUM_4,  GPIO_NUM_5,  GPIO_NUM_6,  GPIO_NUM_7  } },
    { "grey",  { GPIO_NUM_8,  GPIO_NUM_9,  GPIO_NUM_10, GPIO_NUM_11 } },
    { "black", { GPIO_NUM_12, GPIO_NUM_13, GPIO_NUM_14, GPIO_NUM_43 } },
};

// Current tank levels as percentages (0, 25, 50, 75, 100)
static volatile uint8_t tank_levels[NUM_TANKS];

// ---------------------------------------------------------------------------
// GPIO setup — configure all sensor pins as inputs with pull-down
// ---------------------------------------------------------------------------

static void sensors_init(void)
{
    gpio_config_t io_conf = {
        .mode = GPIO_MODE_INPUT,
        .pull_up_en = GPIO_PULLUP_DISABLE,
        .pull_down_en = GPIO_PULLDOWN_DISABLE,
        .intr_type = GPIO_INTR_DISABLE,
        .pin_bit_mask = 0,
    };

    for (int t = 0; t < NUM_TANKS; t++) {
        for (int s = 0; s < NUM_SENSORS; s++) {
            io_conf.pin_bit_mask |= (1ULL << tanks[t].pins[s]);
        }
    }

    ESP_ERROR_CHECK(gpio_config(&io_conf));

    for (int t = 0; t < NUM_TANKS; t++) {
        ESP_LOGI(TAG, "Tank '%s' sensors: GPIO %d/%d/%d/%d (25%%/50%%/75%%/100%%)",
                 tanks[t].name,
                 tanks[t].pins[0], tanks[t].pins[1],
                 tanks[t].pins[2], tanks[t].pins[3]);
    }
}

// ---------------------------------------------------------------------------
// Read sensors and convert to percentage
// Water rises from bottom up, so the level equals the highest triggered
// sensor. e.g., if 25% and 50% are high but 75% is low, level = 50%.
// ---------------------------------------------------------------------------

static uint8_t read_tank_level(const tank_config_t *tank)
{
    uint8_t level = 0;

    for (int s = 0; s < NUM_SENSORS; s++) {
        if (gpio_get_level(tank->pins[s])) {
            level = (s + 1) * 25;  // 25, 50, 75, or 100
        }
    }

    return level;
}

static void poll_sensors(void)
{
    for (int t = 0; t < NUM_TANKS; t++) {
        tank_levels[t] = read_tank_level(&tanks[t]);
    }
}

// ---------------------------------------------------------------------------
// TWAI (CAN) task -- runs independently on core 1
// ---------------------------------------------------------------------------


static void twai_task(void *arg)
{
    // Configure alerts BEFORE any bus activity so no error transitions are missed.
    twai_reconfigure_alerts(CAN_COMMON_ALERTS, NULL);

    // Alerts armed — version broadcast TX failure is caught by the state machine.
    can_common_version_broadcast();

    typedef enum { TX_ACTIVE, TX_PROBING } tx_state_t;
    bool bus_off = false;
    tx_state_t tx_state = TX_ACTIVE;
    int tx_fail_count = 0;
    const int TX_FAIL_THRESHOLD = 3;
    int64_t last_tx_us = 0;
    const int64_t tx_period_us = CAN_STATUS_PERIOD_MS * 1000LL;
    const int64_t tx_probe_period_us = TX_PROBE_INTERVAL_MS * 1000LL;

    while (1) {
        uint32_t triggered;
        twai_read_alerts(&triggered, pdMS_TO_TICKS(CAN_STATUS_PERIOD_MS));

        // Bus-off: stop transmitting, initiate recovery
        if (triggered & TWAI_ALERT_BUS_OFF) {
            ESP_LOGE(TAG, "TWAI bus-off, initiating recovery");
            bus_off = true;
            twai_initiate_recovery();
            // No continue — fall through so RX_DATA in the same poll is still processed.
        }

        // Bus recovered: restart the driver
        if (triggered & TWAI_ALERT_BUS_RECOVERED) {
            ESP_LOGI(TAG, "TWAI bus recovered, restarting");
            twai_start();
            bus_off = false;
            tx_fail_count = 0;
            tx_state = TX_PROBING;
        }

        if (triggered & TWAI_ALERT_ERR_PASS) {
            ESP_LOGW(TAG, "TWAI error passive (no peers ACKing?)");
        }
        if (triggered & TWAI_ALERT_TX_FAILED) {
            if (tx_state == TX_ACTIVE) {
                tx_fail_count++;
                if (tx_fail_count >= TX_FAIL_THRESHOLD) {
                    tx_state = TX_PROBING;
                    ESP_LOGW(TAG, "TWAI no peers detected, entering slow probe");
                }
            }
        }
        if (triggered & TWAI_ALERT_TX_SUCCESS) {
            if (tx_state == TX_PROBING) {
                tx_state = TX_ACTIVE;
                tx_fail_count = 0;
                can_common_version_broadcast();
                ESP_LOGI(TAG, "TWAI probe ACK'd, peer detected, resuming normal TX");
            }
            tx_fail_count = 0;
        }

        // Drain received messages and dispatch
        if (triggered & TWAI_ALERT_RX_DATA) {
            if (tx_state == TX_PROBING) {
                tx_state = TX_ACTIVE;
                tx_fail_count = 0;
                can_common_version_broadcast();
                ESP_LOGI(TAG, "TWAI peer detected via RX, resuming normal TX");
            }
            twai_message_t msg;
            while (twai_receive(&msg, 0) == ESP_OK) {
                if (msg.rtr) continue;

                switch (msg.identifier) {
                case CAN_ID_OTA:
                    if (msg.data_length_code >= 3) {
                        ota_handle_trigger(msg.data, msg.data_length_code);
                    }
                    break;

                case CAN_ID_WIFI_CONFIG:
                    if (msg.data_length_code >= 1) {
                        wifi_config_handle_can(msg.data, msg.data_length_code);
                    }
                    break;

                case CAN_ID_DISCOVERY_TRIGGER:
                    discovery_handle_trigger();
                    break;

                default:
                    break;
                }
            }
        }

        // Check wifi config timeout
        wifi_config_check_timeout();

        // Periodic transmit — water tank levels as percentages
        int64_t now_us = esp_timer_get_time();
        int64_t effective_period = (tx_state == TX_PROBING) ? tx_probe_period_us : tx_period_us;
        if (!bus_off && (now_us - last_tx_us >= effective_period)) {
            last_tx_us = now_us;

            // Message 0x3E: WaterTankLevels
            //   Byte 0: Fresh water level (0-100%)
            //   Byte 1: Grey water level  (0-100%)
            //   Byte 2: Black water level (0-100%)
            twai_message_t m = {
                .identifier = CAN_ID_WATER_TANK_LEVELS,
                .data_length_code = 3,
                .data = {
                    tank_levels[0],  // fresh
                    tank_levels[1],  // grey
                    tank_levels[2],  // black
                }
            };

            twai_transmit(&m, 0);
        }
    }
}

// ---------------------------------------------------------------------------
// Main application
// ---------------------------------------------------------------------------

void app_main(void)
{
    ESP_LOGI(TAG, "=== TrailCurrent Reservoir ===");
    ESP_LOGI(TAG, "Water Tank Level Monitor (contactless sensors to CAN)");

    // Initialize NVS and load WiFi credentials
    ESP_ERROR_CHECK(wifi_config_init());

    char ssid[33] = {0};
    char password[64] = {0};
    if (wifi_config_load(ssid, sizeof(ssid), password, sizeof(password))) {
        ESP_LOGI(TAG, "WiFi credentials loaded from NVS");
    } else {
        ESP_LOGI(TAG, "No WiFi credentials — OTA disabled until provisioned via CAN");
    }

    // Initialize discovery and OTA (must be after wifi_config_init)
    discovery_init();
    ota_init();

    // Initialize water level sensor GPIOs
    sensors_init();

    ESP_LOGI(TAG, "Hostname: %s", wifi_config_get_hostname());

    // CAN runs in its own task so bus errors never block sensor polling
    ESP_ERROR_CHECK(can_common_init(CAN_TX_PIN, CAN_RX_PIN));
    xTaskCreatePinnedToCore(twai_task, "twai", 4096, NULL, 5, NULL, 1);

    // Main task: poll water level sensors periodically
    uint8_t prev_levels[NUM_TANKS] = {0xFF, 0xFF, 0xFF};  // force initial log
    int log_counter = 0;
    while (1) {
        poll_sensors();

        // Log on change or every 10 seconds
        bool changed = false;
        for (int t = 0; t < NUM_TANKS; t++) {
            if (tank_levels[t] != prev_levels[t]) {
                changed = true;
                prev_levels[t] = tank_levels[t];
            }
        }
        if (changed || ++log_counter >= (10000 / SENSOR_POLL_MS)) {
            ESP_LOGI(TAG, "Levels: fresh=%d%% grey=%d%% black=%d%%",
                     tank_levels[0], tank_levels[1], tank_levels[2]);
            log_counter = 0;
        }

        vTaskDelay(pdMS_TO_TICKS(SENSOR_POLL_MS));
    }
}

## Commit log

2026-04-03 Starting project
    [partitions.csv]
2026-04-10 Firmware initial release and case bottom done. 3mf added. Cover still needs to be completed.
    [BodyReservoirCaseBottom.stl, TrailCurrentReservoir.3mf, TrailCurrentReservoirHousing.FCStd]
2026-04-12 Updated 3mf to have ABS settings. FreeCAD assmebly visibility fixes
    [BodyRservoirCaseCover.stl, TrailCurrentReservoir.3mf, TrailCurrentReservoir.blend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]
2026-04-15 Moving to the common CAN library
    [partitions.csv]
2026-06-25 Updates to the CAD design
    [TrailCurrentReservoirHousing.FCStd]
